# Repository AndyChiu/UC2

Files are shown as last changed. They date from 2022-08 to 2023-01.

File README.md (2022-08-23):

# Universal-Century 2

UC2

The Universal-Century 2 (UC2) is a 86-key split keyboard, TKL size with 3-key thumb cluster and encoders. 

This "UC2 Layout", is a derivative of "Willow Layout (v 1.0)" by [Hanachi-ap](https://github.com/hanachi-ap), used under CC BY-SA 4.0.

"UC2 Layout" is licensed under CC BY-SA 4.0 by [AndyChiu](https://github.com/AndyChiu).

Thank you so much Mr. Hanachi!

FDM PCB Board

PCB using FDM 3D printer and hand wiring, Non-factory PCB, Layout design using [Keyboard-layout-editor.com (KLE)](http://www.keyboard-layout-editor.com/) web application, 3D file(.STL) build using [hotswap_pcb_generator](https://github.com/AndyChiu/hotswap_pcb_generator) OpenSCAD script.

* OpenSCAD files : [SCAD](https://github.com/AndyChiu/UC2/tree/main/SCAD)
* 3D files : [STLs](https://github.com/AndyChiu/UC2/tree/main/STLs)
* Build guied: [Chinese](https://ie321mx.blogspot.com/2021/09/choc-v2.html)
* Layout & key matrix PDF files : [PDF](https://github.com/AndyChiu/UC2/tree/main/PDF)
* QMK Firmware : [UC2](https://github.com/AndyChiu/qmk_firmware/tree/uc2_kb/keyboards/handwired/uc2) 

Recommend use [REMAP](https://remap-keys.app) to config VIA key setting, and they support flash firmware on web, just open [UC2 firmware](https://remap-keys.app/catalog/bwCYjD27IZM8dbOddvCt/firmware) to Flash!

Left Hand
Right Hand

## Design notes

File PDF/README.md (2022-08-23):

* "Martix.pdf" - Matrix info. for wire work.
* "keymap_cheatsheet_universalcentury2.pdf" - default Layout, Generated by [REMAP](https://remap-keys.app/), add [CC BY-SA 4.0](https://creativecommons.org/licenses/by-sa/4.0/deed.en) info.

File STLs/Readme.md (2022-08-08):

### For Gateron KS27 switch
* pcb_L_KS27.stl
* pcb_R_KS27.stl

### For Choc V1 16mm spacing
* pcb_L_ChocV1_16mm.stl
* pcb_R_ChocV1_16mm.stl

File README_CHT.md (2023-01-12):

# UC2鍵盤(Universal-Century 2)

UC2

UC2鍵盤(Universal-Century 2) 是左右分離式鍵盤，有86顆鍵，有完整的F鍵區，為TKL尺寸的鍵盤，單面包含了3顆拇指鍵與編碼器。

UC2鍵盤的Layout配置，是由 Willow Layout (v 1.0) 發展而來，該Layout由 [Hanachi-ap](https://github.com/hanachi-ap) 開發，並使用CC BY-SA 4.0發布。

UC2 Layout也是依照CC BY-SA 4.0規範發布，並由 [AndyChiu](https://github.com/AndyChiu) 維護。

非常感謝 Hanachi 先生的自由發佈精神!

FDM PCB Board

PCB的部分，採用FDM方式的3D印表機列印，線路採用CAT5或者CAT6的網路線內芯並且手動拉線，而非工廠製作的PCB。
Layout設計採用[Keyboard-layout-editor.com (KLE)](http://www.keyboard-layout-editor.com/) 網頁程式處理，列印的3D檔案(.STL)是由 [hotswap_pcb_generator](https://github.com/AndyChiu/hotswap_pcb_generator) OpenSCAD 腳本程式來處理。

* OpenSCAD 檔案 : [SCAD](https://github.com/AndyChiu/UC2/tree/main/SCAD)
* 3D 檔案 : [STLs](https://github.com/AndyChiu/UC2/tree/main/STLs)
* 製作指南: [中文](https://ie321mx.blogspot.com/2021/09/choc-v2.html)
* Layout 與 key matrix 說明文件 : [PDF](https://github.com/AndyChiu/UC2/tree/main/PDF)
* QMK Firmware : [UC2](https://github.com/AndyChiu/qmk_firmware/tree/uc2_kb/keyboards/handwired/uc2) 

強烈建議使用 [REMAP](https://remap-keys.app) 來設定鍵盤，可以透過 VIA 技術來設定個別按鍵功能，且支援網頁燒錄韌體至MCU，可由此開啟頁面 [UC2 firmware](https://remap-keys.app/catalog/bwCYjD27IZM8dbOddvCt/firmware) 進行燒錄!

Left Hand
Right Hand

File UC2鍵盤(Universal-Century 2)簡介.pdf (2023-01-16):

# UC2鍵盤簡介

Choc V1軸版本 + 玻璃鍵帽

UC2 (Universal-Century 2) 規格與特性：

- 左右分離式
- TKL尺⼨86鍵
- 三拇指鍵
- 雙編碼器
- 雙曲線 UC2 Layout
- ⼿⼯PCB
- 玻璃鍵帽

關於 UC2 Layout：

由 Hanachi-ap 開發 Willow Layout (v 1.0) 修改⽽來，為 CC BY-SA 4.0 授權，為縱 向橫向雙曲線設計。原始Willow Layout介紹圖：

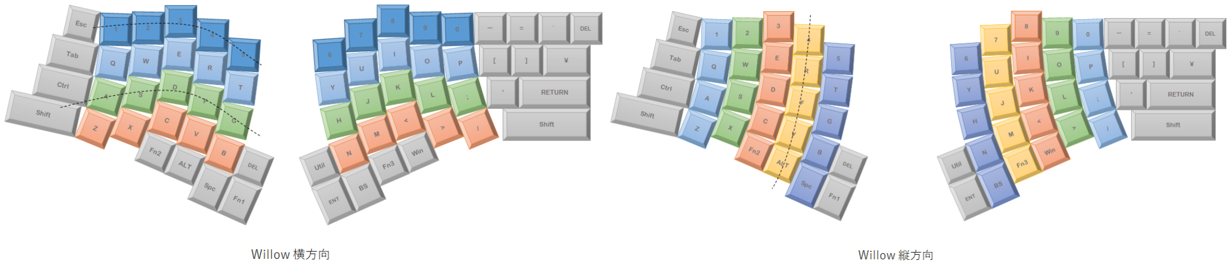
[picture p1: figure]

取⾃於 https://coal.hatenablog.com/entry/2020/12/04/231923

### 關於 ⼿⼯ PCB：

由 hotswap_pcb_generator 此 OpenSCAD 腳本程式，轉換 Keyboard-layout-editor.com (KLE) 建立的 Layout JSON 檔案，再經過相關設定與 調整後，產⽣3D模型，以FDM 3D印表機列印，完成後進⾏⼿⼯接線，線材為網路 線內芯銅線，此接線⽅式，可建立有熱插拔特性的⼿⼯PCB。

### 關於軸體類型：

此鍵盤使⽤了 Choc V1(PG1350)、Choc Mini (PG1232)、Gateron KS27混和軸體 ，主要使⽤的是Choc V1(PG1350)軸。

### 玻璃鍵帽：

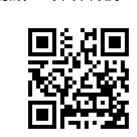
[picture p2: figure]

採⽤雙平⾯正⽅形玻璃，尺⼨為 12 x 12mm，底圖紙張為UV膠專⽤紙，以環氧樹 脂黏合，最後再加上Choc V1軸的接腳。

網址: https://github.com/AndyChiu/UC2

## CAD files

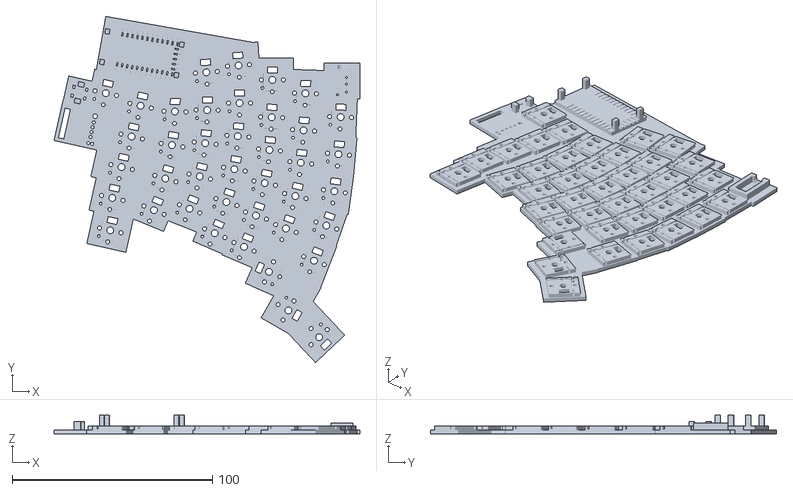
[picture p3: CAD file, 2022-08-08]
STLs/pcb_L_ChocV1_16mm.stl
152.9 x 173.0 x 9.25

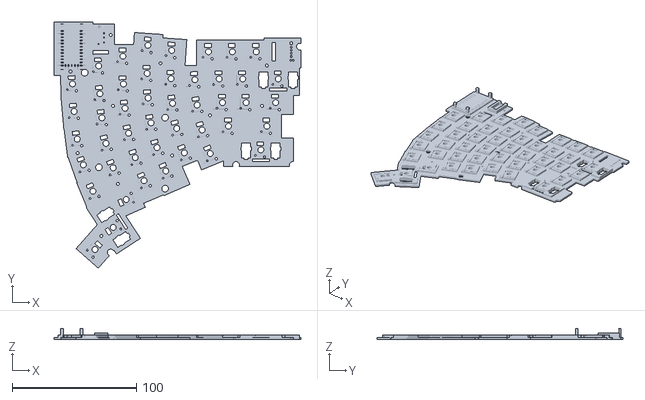
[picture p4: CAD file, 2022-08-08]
STLs/pcb_R_KS27.stl
199.0 x 198.5 x 9.25

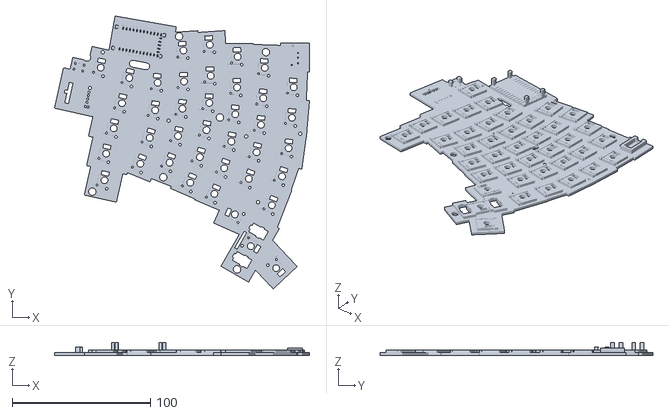
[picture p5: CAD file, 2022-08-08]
STLs/pcb_L_KS27.stl
184.7 x 197.6 x 9.25

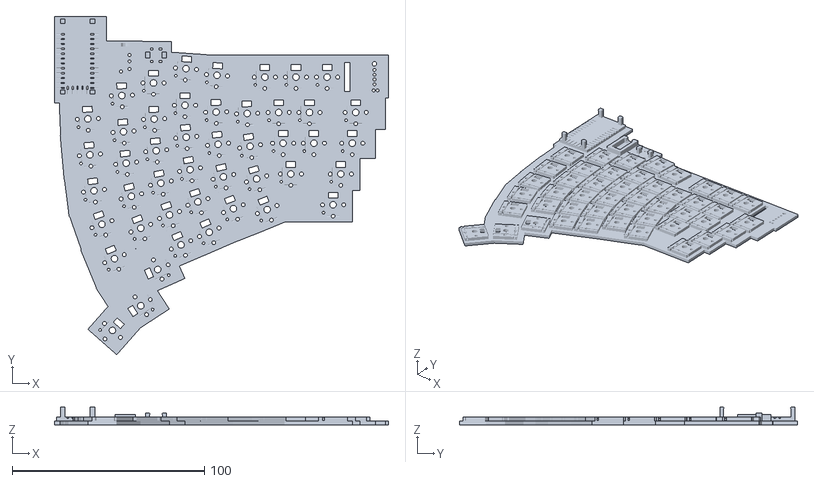
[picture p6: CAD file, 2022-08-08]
STLs/pcb_R_ChocV1_16mm.stl
173.6 x 175.9 x 9.25

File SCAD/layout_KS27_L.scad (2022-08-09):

include <parameters.scad>
include <stabilizer_spacing.scad>

/*
UC2 Left KS27 19.05mm 
layout_KS27_L.scad

parameters.scad :
	switch_type = "ks27"; 
	include <parameters_mcu_ProMicro.scad>
	mcu_type = "socketed";  // [bare, socketed, socketed2]
	unit = 19.05;
*/


/* [Layout Values] */
/* Layout Format (each key):
    [
        [                                       // Location Data
            [x_location, y_location],
            key_size,
            [rotation, rotation_x, rotation_y],
        ],
        [                                       // Borders
            top_border,
            bottom_border,
            left_border,
            right_border
        ],
        extra_data                              // Extra data (depending on component type)
    ]
*/

// Keyswitch Layout
//     (extra_data = rotate_column)
base_switch_layout = [
  //3
[[[4.2010498687664,1.19580052493438],1,[-360,4.7010498687664,1.69580052493438]],[3,2,2,2],[false,switch_type]],
  //2
[[[3.18951364829396,1.41275942257218],1,[-1,3.68951364829396,1.91275942257218]],[3,2,2,2],[false,switch_type]],
  //1
[[[2.18219223097113,1.45834776902887],1,[-1.80000000000001,2.68219223097113,1.95834776902887]],[4,2,3,1],[false,switch_type]],
  //F4
[[[6.25673742782152,0.8918022572178499],1,[-1.89999999999998,6.75673742782152,1.39180225721785]],[4.5,3,2,3],[false,switch_type]],
  //4
[[[5.2037456167979,1.6375524934383199],1,[-2.39999999999998,5.7037456167979,2.13755249343832]],[1,3,2,3],[false,switch_type]],
  //F5
  [[[7.35702645669291,1.6328280839895002],1,[-2.39999999999998,7.85702645669291,2.1328280839895]],[2,3,4,1],[false,switch_type]],
  //5
[[[6.19913774278215,2.04750839895013],1,[-3.89999999999998,6.69913774278215,2.54750839895013]],[3,2,2,2],[false,switch_type]],
  //E
[[[4.14670640419947,2.22828965879265],1,[-4.5,4.64670640419947,2.72828965879265]],[2,2,2,2],[false,switch_type]],
  //R
  [[[5.13627874015748,2.65789049868766],1,[-5.10000000000002,5.63627874015748,3.15789049868766]],[2,2,2,2],[false,switch_type]],
  //F6
[[[7.29008451443569,2.7917487664042],1,[-5.10000000000002,7.79008451443569,3.2917487664042]],[3,3,3,2],[false,switch_type]],
  //W
[[[3.12693832020997,2.44626593175853],1,[-5.89999999999998,3.62693832020997,2.94626593175853]],[2,2,2,2],[false,switch_type]],
  //T
[[[6.1117298687664,3.05872372703412],1,[-6,6.6117298687664,3.55872372703412]],[2,2,2,3],[false,switch_type]],
  //Home
[[[7.16137942257218,3.9496355380577404],1,[-7.80000000000001,7.66137942257218,4.44963553805774]],[3,3,3,2],[false,switch_type]],
  //Q
[[[2.08866141732283,2.50596236220472],1,[-9,2.58866141732283,3.00596236220472]],[2,3,2,2],[false,switch_type]],
  //D
[[[4.03900157480315,3.25851291338583],1,[-9.89999999999998,4.53900157480315,3.75851291338583]],[2,3,2,2],[false,switch_type]],
  //F
[[[4.98587826771653,3.6925105511811003],1,[-11.5,5.48587826771653,4.1925105511811]],[2,2,2,2],[false,switch_type]],
  //ESC
[[[0.02294834645669297,0.88521527559055],1,[-12.6,0.522948346456693,1.38521527559055]],[3,1,1,3],[false,switch_type]],
  //Win
[[[0.03588797900262397,5.16867984251968],1.25338582677165,[-12.6,0.662580892388451,5.66867984251968]],[1,3,1+0.126692913385825*unit*mm,1+0.126692913385825*unit*mm],[false,switch_type]],
  //Shift
[[[0.09940503937007905,4.15555648293963],1.25338582677165,[-12.6,0.726097952755906,4.65555648293963]],[2,2,1+0.126692913385825*unit*mm,1+0.126692913385825*unit*mm+3],[false,switch_type]],
  //CAPS
[[[0.143312073490809,3.19334304461942],1.74540682414698,[-12.6,1.0160154855643,3.69334304461942]],[1,1,1+0.37270341207349*unit*mm,1+0.37270341207349*unit*mm],[false,switch_type]],
  //TAB
[[[0.578853858267721,2.24007091863517],1.4997375328084,[-12.6,1.32872262467192,2.74007091863517]],[3,1,1+0.24986876640419997*unit*mm+2,1+0.24986876640419997*unit*mm],[false,switch_type]],
  //~
[[[1.10851265091864,1.27786619422572],1,[-12.6,1.60851265091864,1.77786619422572]],[1,1,2,1],[false,switch_type]],
  //S
[[[2.95647107611549,3.4849132808399],1,[-13.2,3.45647107611549,3.9849132808399]],[3,3,2,2],[false,switch_type]],
  //G
[[[5.94397060367454,4.09814887139108],1,[-13.5,6.44397060367454,4.59814887139108]],[3,3,2,3],[false,switch_type]],
  //A
[[[1.8832476115485601,3.55154104986877],1,[-16.8,2.38324761154856,4.05154104986877]],[3,3,2,2],[false,switch_type]],
  //C
[[[3.7898355380577398,4.28506818897638],1,[-18.1,4.28983553805774,4.78506818897638]],[3,3,2,2],[false,switch_type]],
  //V
[[[4.71412482939632,4.7080087664042],1,[-19,5.21412482939632,5.2080087664042]],[3,3,2,2],[false,switch_type]],
  //End
[[[6.91154635170604,5.01863627296588],1,[-19.1,7.41154635170604,5.51863627296588]],[3,3,3,1],[false,switch_type]],
  //B
[[[5.64927433070866,5.1127045144357],1,[-20.6,6.14927433070866,5.6127045144357]],[3,5,2,3],[false,switch_type]],
  //Insert
[[[6.52576729658793,6.11656923884514],1,[-21.3,7.02576729658793,6.61656923884514]],[4,3,3,1],[false,switch_type]],
  //X
[[[2.63870776902887,4.49471900262467],1,[-21.5,3.13870776902887,4.99471900262467]],[3,4,3,2],[false,switch_type]],
  //Z
[[[1.52789732283465,4.5381582152231],1,[-22.4,2.02789732283465,5.0381582152231]],[2,1,3,2],[false,switch_type]],
  //Right
[[[4.34115427821522,5.68306650918635],1,[-23.1,4.84115427821522,6.18306650918635]],[2,1,2,2],[false,switch_type]],
  //Left
[[[3.42666650918635,5.25746094488189],1,[-23.5,3.92666650918635,5.75746094488189]],[2,1,2,2],[false,switch_type]],
  //~
[[[5.10419716535433,7.670040682414699],2.24409448818898,[-119.9,6.22624440944882,8.1700406824147]],[2,2,1+0.62204724409449*unit*mm,1+0.62204724409449*unit*mm+1],[false,switch_type]],
  //Ctrl
[[[6.56325832020997,8.50632745406824],1.2498687664042,[-136.9,7.18819270341207,9.00632745406824]],[1,5,1+0.12493438320210004*unit*mm,1+0.12493438320210004*unit*mm],[false,switch_type]],
  //Alt
[[[4.9939922834645705,6.46455790026247],1.2498687664042,[-294,5.61892666666667,6.96455790026247]],[2,2,1+0.12493438320210004*unit*mm,1+0.12493438320210004*unit*mm+3],[false,switch_type]],
  //F1
[[[3.16187711286089,0.23399748031496104],1,[-356,3.66187711286089,0.733997480314961]],[3,1,2,2],[false,switch_type]],
  //F2
[[[4.16765139107611,0.018249448818898006],1,[-356,4.66765139107611,0.518249448818898]],[1,1,2,2],[false,switch_type]],
  //F3
[[[5.22467202099738,0.47100750656168],1,[-359.9,5.72467202099738,0.97100750656168]],[1,3,2,2],[false,switch_type]],
];

// MCU Position(s)
//base_mcu_layout = [];
base_mcu_layout = [
    [[[-0.8,1],mcu_h_unit_size,[80,0,0]],[1,6,4,1]],
];

// TRRS Position(s)
//base_trrs_layout = [];
 base_trrs_layout = [
     [[[7.4,0.5],1,[0,0,0.5]],[1,1,1,1]],
 ];

// Plate Layout (if different than PCB)
//     (extra_data = component_type)
base_plate_layout = [
    concat(
//        slice(base_switch_layout, [0,-2]),
//        [
//            [[[6,0.5],mcu_h_unit_size],[-2,0,3,0], ["mcu"]],
//            [[[6.5,2.5],1,[-90,7,3]],[0,0.5*h_unit,0,5.97], ["trrs"]]
//        ]
    ),
    [
 [[[0.1389,0.7639],1,[0,0,0]],[0,0,0,0]],
 [[[2.7951,1.2674],1,[0,0,0]],[0,0,0,0]],
 [[[2.7604,0.2604],1,[0,0,0]],[0,0,0,0]],
 [[[4.7222,0],1,[0,0,0]],[0,0,0,0]],
 [[[4.1493,0.2257],1,[0,0,0]],[0,0,0,0]],
 [[[6.9444,1.1806],1,[0,0,0]],[0,0,0,0]],
 [[[7.6563,0.8854],1,[0,0,0]],[0,0,0,0]],
 [[[7.7257,2.3785],1,[0,0,0]],[0,0,0,0]],
 [[[7.4479,4.7222],1,[0,0,0]],[0,0,0,0]],
 [[[6.6667,7.1007],1,[0,0,0]],[0,0,0,0]],
 [[[7.3438,8.0208],1,[0,0,0]],[0,0,0,0]],
 [[[6.3194,8.9583],1,[0,0,0]],[0,0,0,0]],
 [[[5.4688,8.4896],1,[0,0,0]],[0,0,0,0]],
 [[[4.7049,7.9861],1,[0,0,0]],[0,0,0,0]],
 [[[4.6007,6.7014],1,[0,0,0]],[0,0,0,0]],
 [[[3.7326,5.9896],1,[0,0,0]],[0,0,0,0]],
 [[[2.6563,5.1042],1,[0,0,0]],[0,0,0,0]],
 [[[2.0833,5.2083],1,[0,0,0]],[0,0,0,0]],
 [[[1.4236,5.3472],1,[0,0,0]],[0,0,0,0]],
 [[[1.059,5.8507],1,[0,0,0]],[0,0,0,0]],
 [[[0,5.5903],1,[0,0,0]],[0,0,0,0]],
 [[[0,4.4444],1,[0,0,0]],[0,0,0,0]],
 [[[0.0868,2.9861],1,[0,0,0]],[0,0,0,0]],
 [[[-0.825,2.6563],1,[0,0,0]],[0,0,0,0]],
 [[[-0.4861,1.4583],1,[0,0,0]],[0,0,0,0]],

//        [[[0,-0.3],1.5,[0,0,0]],[1,1,1,1]],
//        [[[7,-0.5],1.5,[0,0,0]],[1,1,1,1]],
//        [[[7,8],1.5,[0,0,0]],[1,1,1,1]],
//        [[[7,8],1.5,[0,0,0]],[1,1,1,1]],
//        [[[0,5.5],1.5,[0,0,0]],[1,1,1,1]],
//        [[[4.875,4.625],1.5,[60,4.875,4.625]],[30*mm,1,0.25*unit*mm,17.11*mm]],
//        [[[4.875,5.625],1.5,[60,4.875,4.625]],[1,0,0.25*unit*mm,17.11*mm]],
    ]

];

// Whether to only use base_plate_layout to generate the plate footprint
use_plate_layout_only = true;

// Stabilizer layout
//     (extra_data = [key_size, left_offset, right_offset, switch_offset=0])
//     (see stabilizer_spacing.scad for presets)
base_stab_layout = [
[[[5.10419716535433,7.670040682414699],2.24409448818898,[-119.9,6.22624440944882,8.1700406824147]],[1,2,1,1],2_25u],

];

// Standoff hole layout
//     (extra_data = [standoff_integration_override, standoff_attachment_override])
// base_standoff_layout = [];
base_standoff_layout = [
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

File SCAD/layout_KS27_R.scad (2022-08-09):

include <parameters.scad>
include <stabilizer_spacing.scad>

/*
UC2 Right KS27 19.05mm 
layout_KS27_R.scad

parameters.scad :
	switch_type = "ks27"; 
	include <parameters_mcu_ProMicro.scad>
	mcu_type = "socketed";  // [bare, socketed, socketed2]
	unit = 19.05;
*/


/* [Layout Values] */
/* Layout Format (each key):
    [
        [                                       // Location Data
            [x_location, y_location],
            key_size,
            [rotation, rotation_x, rotation_y],
        ],
        [                                       // Borders
            top_border,
            bottom_border,
            left_border,
            right_border
        ],
        extra_data                              // Extra data (depending on component type)
    ]
*/

// Keyswitch Layout
//     (extra_data = rotate_column)
base_switch_layout = [
//8
  [[[3.23937007874016,1.12913385826772],1,[-360,3.73937007874016,1.62913385826772]],[3,2,2,2],[false,switch_type]],
//PrtSc
  [[[5.83412073490814,0.21469816272965903],1,[-360,6.33412073490814,0.714698162729659]],[1,2,1,1],[false,switch_type]],
//-
  [[[6.28346456692913,1.36272965879265],1,[-360,6.78346456692913,1.86272965879265]],[2,1,2,1],[false,switch_type]],
//[
  [[[6.42729658792651,2.36220472440945],1,[-360,6.92729658792651,2.86220472440945]],[2,3,2,2],[false,switch_type]],
//'
  [[[6.67926509186352,3.36220472440945],1,[-360,7.17926509186352,3.86220472440945]],[2,4,2,4],[false,switch_type]],
//Scroll Lock
  [[[6.84566929133858,0.21417322834645702],1,[-360,7.34566929133858,0.714173228346457]],[1,2,2,2],[false,switch_type]],
//=
  [[[7.28346456692913,1.36220472440945],1,[-360,7.78346456692913,1.86220472440945]],[2,1,1,1],[false,switch_type]],
//]
  [[[7.42782152230971,2.36220472440945],1,[-360,7.92782152230971,2.86220472440945]],[1,1,1,1],[false,switch_type]],
//Pause Break
  [[[7.85564304461942,0.21417322834645702],1,[-360,8.35564304461942,0.714173228346457]],[1,3,2,2],[false,switch_type]],
//Shift
  [[[7.180052493438319,4.36272965879265],2.74278215223097,[-360,8.55144356955381,4.86272965879265]],[1,3,3+0.871391076115485*unit*mm,1+0.871391076115485*unit*mm],[false,switch_type]],
//Enter
  [[[8.178477690288709,3.36272965879265],1.2498687664042,[-360,8.80341207349081,3.86272965879265]],[1,2,3+0.12493438320210004*unit*mm,1+0.12493438320210004*unit*mm],[false,switch_type]],
//\
  [[[8.427034120734907,2.36220472440945],1.49606299212598,[-360,9.1750656167979,2.86220472440945]],[1,1,1+0.24803149606299002*unit*mm,1+0.24803149606299002*unit*mm],[false,switch_type]],
//Backspace
  [[[8.289238845144359,1.36115485564304],1.99527559055118,[-360,9.28687664041995,1.86115485564304]],[1,3,2+0.49763779527559004*unit*mm,0+0.49763779527559004*unit*mm],[false,switch_type]],
//MUTE
//  [[[9.01706036745407,0.21443569553805797],1,[-360,9.51706036745407,0.714435695538058]],[2,3,3,2],[false,switch_type]],
//F10
  [[[2.21627307086614,0.40353317585301895],1,[-0.100000000000023,2.71627307086614,0.903533175853019]],[1,3,2,2],[false,switch_type]],
//F11
  [[[3.27211333333333,-0.05971926509186398],1,[-4,3.77211333333333,0.440280734908136]],[1,1,2,2],[false,switch_type]],
//F12
  [[[4.27893748031496,0.15550383202099705],1,[-4,4.77893748031496,0.655503832020997]],[1,3,2,2],[false,switch_type]],
//MENU
  [[[0.9089575328084,8.57792288713911],1.2498687664042,[-41.4,1.5338919160105,9.07792288713911]],[5,1,1+0.12493438320210004*unit*mm,1+0.12493438320210004*unit*mm],[false,switch_type]],
//Enter
  [[[1.18237391076115,7.64275275590551],2.24409448818898,[-236.9,2.30442115485564,8.14275275590551]],[1,3,0.62204724409449*unit*mm,3+0.62204724409449*unit*mm],[false,switch_type]],
//Space
  [[[2.22944593175853,6.46455790026247],1.2498687664042,[-246,2.85438031496063,6.96455790026247]],[1,2,1+0.12493438320210004*unit*mm,4+0.12493438320210004*unit*mm],[false,switch_type]],
//Down
  [[[4.02771637795276,5.25539994750656],1,[-336.5,4.52771637795276,5.75539994750656]],[3,5,1,3],[false,switch_type]],
//Up
  [[[3.11043228346457,5.66590414698163],1,[-336.9,3.61043228346457,6.16590414698163]],[3,4.5,1,3],[false,switch_type]],
//Delete
  [[[0.9483960104986899,6.11239632545932],1,[-337.4,1.44839601049869,6.61239632545932]],[2,2,1,3],[false,switch_type]],
///
  [[[5.90952461942257,4.51800976377953],1,[-337.6,6.40952461942257,5.01800976377953]],[2,1,2,3],[false,switch_type]],
//.
  [[[4.81351091863517,4.48743322834646],1,[-338.5,5.31351091863517,4.98743322834646]],[2,1,2,2],[false,switch_type]],
//N
  [[[1.8033827296587899,5.121683832021],1,[-338.8,2.30338272965879,5.621683832021]],[3,3,1,3],[false,switch_type]],
//Page Down
  [[[0.54108251968504,4.99436257217848],1,[-340.6,1.04108251968504,5.49436257217848]],[2,2,1,3],[false,switch_type]],
//M
  [[[2.73617207349081,4.69356603674541],1,[-341,3.23617207349081,5.19356603674541]],[2,2,2,2],[false,switch_type]],
//,
  [[[3.6591268766404204,4.26926251968504],1,[-341.9,4.15912687664042,4.76926251968504]],[2,1,1,1],[false,switch_type]],
//;
  [[[5.56513737532808,3.5205274540682403],1,[-343.2,6.06513737532808,4.02052745406824]],[2,2,2,2],[false,switch_type]],
//H
  [[[1.4990631496063,4.08706404199475],1,[-345.8,1.9990631496063,4.58706404199475]],[2,1,1,1],[false,switch_type]],
//L
  [[[4.48875454068241,3.45524419947507],1,[-346.8,4.98875454068241,3.95524419947507]],[2,2,2,2],[false,switch_type]],
//J
  [[[2.45726934383202,3.6581456167979],1,[-348.5,2.95726934383202,4.1581456167979]],[2,2,2,2],[false,switch_type]],
//K
  [[[3.40383097112861,3.21970230971129],1,[-350.1,3.90383097112861,3.71970230971129]],[2,2,2,2],[false,switch_type]],
//P
  [[[5.3537532808399,2.46516624671916],1,[-351,5.8537532808399,2.96516624671916]],[2,2,2,2],[false,switch_type]],
//Page Up
  [[[0.28307133858267697,3.9074064041994703],1,[-352.7,0.783071338582677,4.40740640419947]],[3,3,1,3],[false,switch_type]],
//Y
  [[[1.32852776902887,3.01004267716535],1,[-354,1.82852776902887,3.51004267716535]],[2,2,2,2],[false,switch_type]],
//O
  [[[4.31433989501312,2.39625375328084],1,[-354.1,4.81433989501312,2.89625375328084]],[2,2,2,2],[false,switch_type]],
//F7
  [[[0.15097690288713905,2.73948482939633],1,[-354.9,0.650976902887139,3.23948482939633]],[3,3,1,3],[false,switch_type]],
//U
  [[[2.30425774278215,2.60510162729659],1,[-354.9,2.80425774278215,3.10510162729659]],[2,2,2,2],[false,switch_type]],
//I
  [[[3.28031496062992,2.16797900262467],1,[-355.5,3.78031496062992,2.66797900262467]],[2,2,2,2],[false,switch_type]],
//6
  [[[1.24165742782152,1.9892370078740198],1,[-356.1,1.74165742782152,2.48923700787402]],[3,2,2,2],[false,switch_type]],
//F8
  [[[0.08353564304461902,1.5724212598425198],1,[-357.6,0.583535643044619,2.07242125984252]],[1,2,1,2],[false,switch_type]],
//7
  [[[2.23734141732283,1.57714566929134],1,[-357.6,2.73734141732283,2.07714566929134]],[2,2,2,2],[false,switch_type]],
//F9
  [[[1.18954582677165,0.81213475065617],1,[-358.1,1.68954582677165,1.31213475065617]],[1,1,2,1],[false,switch_type]],
//0
  [[[5.25883265091863,1.39677034120735],1,[-358.2,5.75883265091863,1.89677034120735]],[2,2,2,3],[false,switch_type]],
//9
  [[[4.25145590551181,1.34892036745407],1,[-359,4.75145590551181,1.84892036745407]],[2,2,2,2],[false,switch_type]],
];


// MCU Position(s)
base_mcu_layout = [
    [[[-0.2,-0.5],mcu_h_unit_size,[0,0,0]],[1,4,0,3]],
];

// EC11 Position(s)
base_ec11_layout = [
//    [[[9.01706036745407,0.21443569553805797],1,[-360,9.51706036745407,0.714435695538058]],[2,3,3,2]],

];


// EVQWGD001 Position(s)
base_evqwgd001_layout = [
    [[[9.01706036745407,0.21443569553805797],1,[-360,9.51706036745407,0.714435695538058]],[2,3,3,2]],

];

// TRRS Position(s)
base_trrs_layout = [
     [[[1.3,-0.4],1,[0,0,0]],[1,1,1,1]],
];

// Plate Layout (if different than PCB)
//     (extra_data = component_type)
base_plate_layout = [];

// Whether to only use base_plate_layout to generate the plate footprint
use_plate_layout_only = false;

// Stabilizer layout
//     (extra_data = [key_size, left_offset, right_offset, switch_offset=0])
//     (see stabilizer_spacing.scad for presets)
base_stab_layout = [
[[[1.18237391076115,7.64275275590551],2.24409448818898,[-236.9,2.30442115485564,8.14275275590551]],[1,2,1,1],2_25u],
[[[7.180052493438319,4.36272965879265],2.74278215223097,[-360,8.55144356955381,4.86272965879265]],[1,2,1,1],2_75u],
[[[8.289238845144359,1.36115485564304],1.99527559055118,[-360,9.28687664041995,1.86115485564304]],[1,2,1,1],2u],
];

// Standoff hole layout
//     (extra_data = [standoff_integration_override, standoff_attachment_override])
base_standoff_layout = [
    //L0V2
    [[[0.3,4.5]],[0,0,0,0]],

    //L1V1
    //[[[0,-1.3]],[0,0,0,0],["plate", "backplate"]],
    //L1V2-1
    [[[0,1.05]],[0,0,0,0]],
    //L1V2
    [[[0.6,1.1]],[0,0,0,0],["plate", "backplate"]],


   //L1V3
    [[[1.2,5.1]],[0,0,0,0],["plate", "backplate"]],
   //L1V3-2
    [[[2,5.8]],[0,0,0,0]],



   //L1V4
    [[[0.6,7.5]],[0,0,0,0],["plate", "backplate"]],
   //L1V5
    [[[1.7,8.7]],[0,0,0,0],["plate", "backplate"]],
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

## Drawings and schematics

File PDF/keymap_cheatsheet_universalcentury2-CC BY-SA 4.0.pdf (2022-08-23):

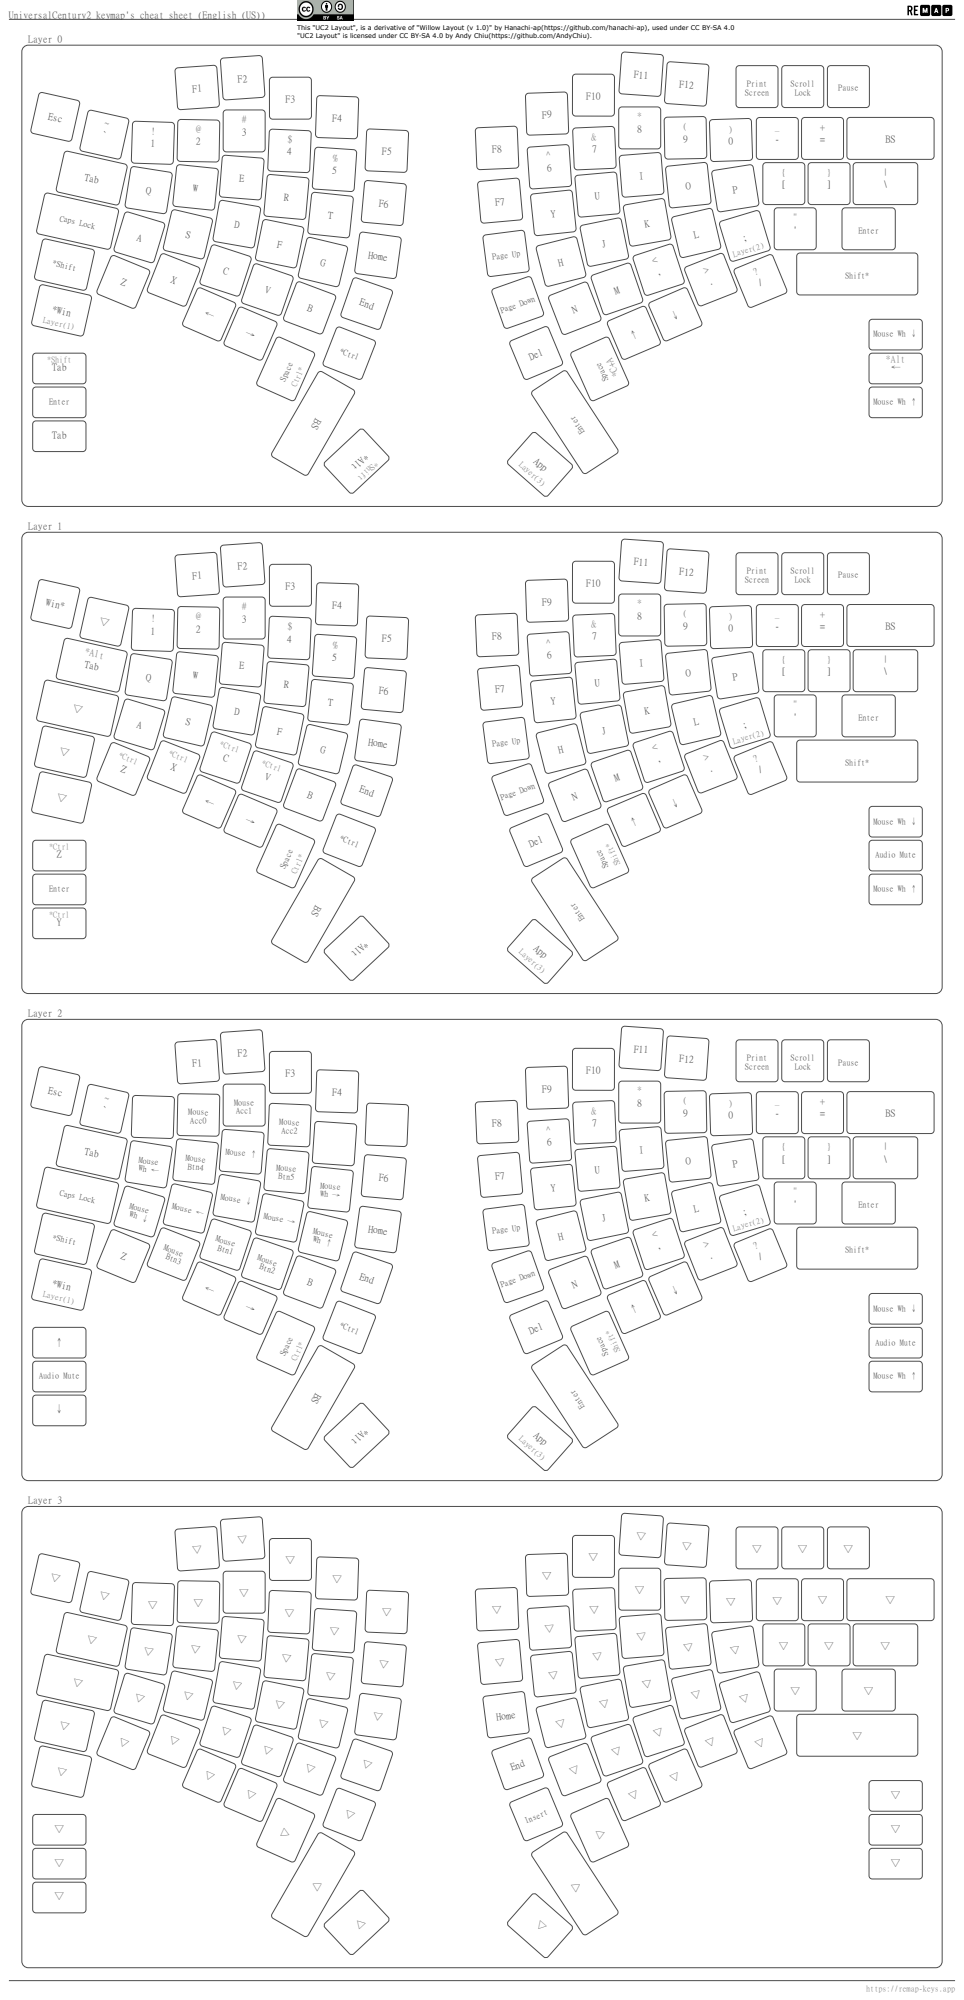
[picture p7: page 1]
Layer 0; *Alt ←; Enter; Mouse Wh ↓; *Shift Tab; Mouse Wh ↑; Tab; Print Screen; Scroll Lock; Pause; Shift*; Home; Esc; *Win Layer(1); *Shift; Caps Lock; End; *Ctrl; App Layer(3); Space; Space Ctrl*; Del; Page Down; , ; Layer(2); Page Up; Layer 1; Audio Mute; *Ctrl Z; *Ctrl Y; Win*; *Alt Tab; *Ctrl C *Ctrl; *Ctrl X *Ctrl Z; Layer 2; Mouse Acc1; Mouse Acc0; Mouse Acc2; Mouse ↑; Mouse Btn5 F6; Mouse Btn4; Mouse Wh →; Mouse Wh ←; Mouse ↓; Mouse →; Mouse ←; Mouse Btn1 Mouse; Btn2; Mouse; Btn3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

UniversalCentury2 keymap's cheat sheet (English (US))

This "UC2 Layout", is a derivative of "Willow Layout (v 1.0)" by Hanachi-ap(https://github.com/hanachi-ap), used under CC BY-SA 4.0
"UC2 Layout" is licensed under CC BY-SA 4.0 by Andy Chiu(https://github.com/AndyChiu).

https://remap-keys.app

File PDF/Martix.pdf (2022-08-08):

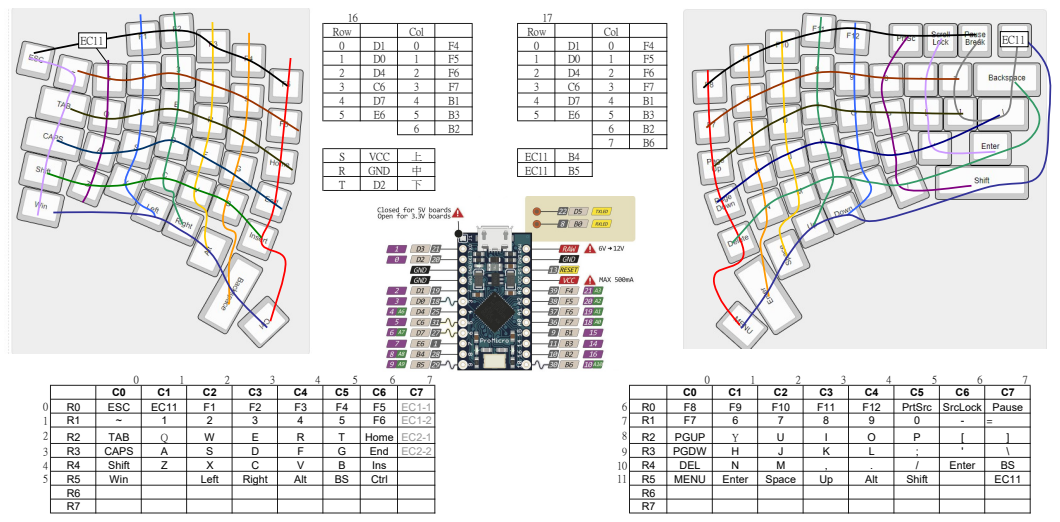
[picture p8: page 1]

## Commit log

2022-08-09 update files
    [layout_KS27_L.scad, layout_KS27_R.scad]
2023-01-12 Create README_CHT.md
    中文說明
